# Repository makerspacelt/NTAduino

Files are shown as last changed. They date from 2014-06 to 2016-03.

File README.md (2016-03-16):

NTAduino
========

Repo for [No Trolls Allowed](http://notrollsallowed.com/) Arduino workshop

[NTA on GitHub](https://github.com/ntacamp)

### User notes
* Download USBasp drivers from [fischl.de](http://www.fischl.de/usbasp/usbasp-windriver.2011-05-28.zip).
* Copy NTAduino board description to boards.txt file from [here](https://github.com/makerspacelt/NTAduino/blob/master/arduino_patch/hardware/arduino/boards.txt)
* Press and hold reset button since board connecting to PC until all code is uploaded to the baord.

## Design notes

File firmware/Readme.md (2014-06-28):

NTAduino V0.1
====================
A project for [No Trolls allowed 2014](http://2014.notrollsallowed.com/)

Idea is to make a affordable, easy to make, minimal design arduino like board. And use it to teach people build and use it without any previous experience.

#### Usage ####
Firmware is stored into ATMega8 boot loader and acts as a USBasp programmer. To enter programing "upload" mode Hold SW1 (Refer to circuit diagram)

#### Compilation ####
- **make** - compile to hex binary
- **make flash** - write the boot loader
- **make fuse** - write fuse bits High: **0xC0** Low: **0x9F**

#### Licensing stuff ####
This project is a clone of [USBAspLoader](http://www.obdev.at/products/vusb/usbasploader.html) with a added small update
to accept SET_ISP_SCK instruction from avrdude (to remove the warning)

Which is build on [V-USB](http://www.obdev.at/products/vusb/index.html)
See *License.txt* fot a full license

#### Legal Disclaimer ####
We are not responsible for any possible damage or any other form of destruction.
If $*it will hit the fan while using this software we will not be held responsible for :)
Just don't ever divide by 0 on a ATMega

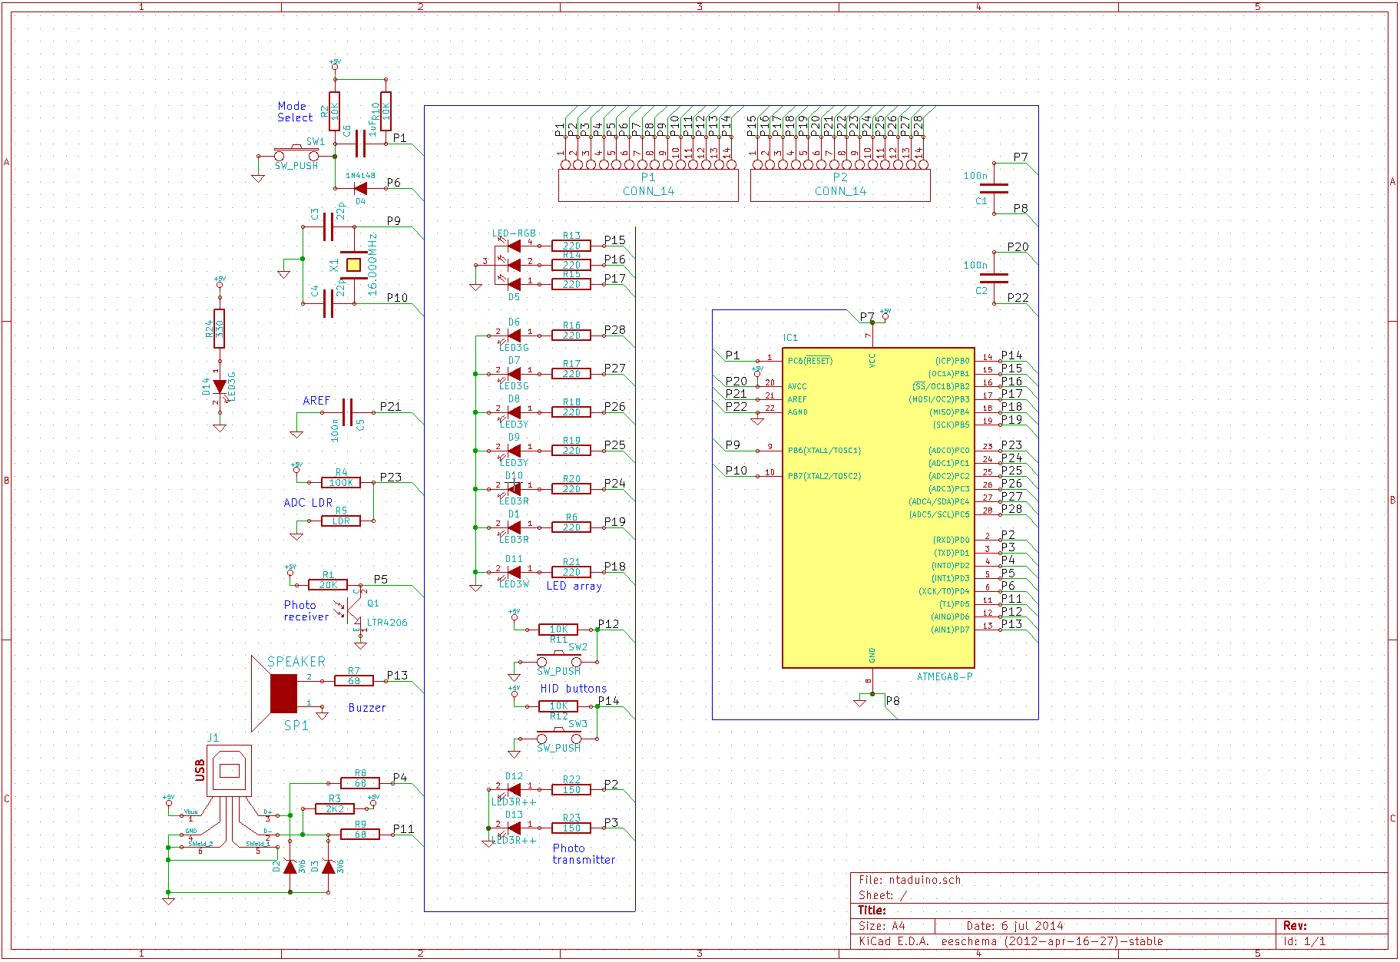
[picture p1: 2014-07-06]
images/sch.png

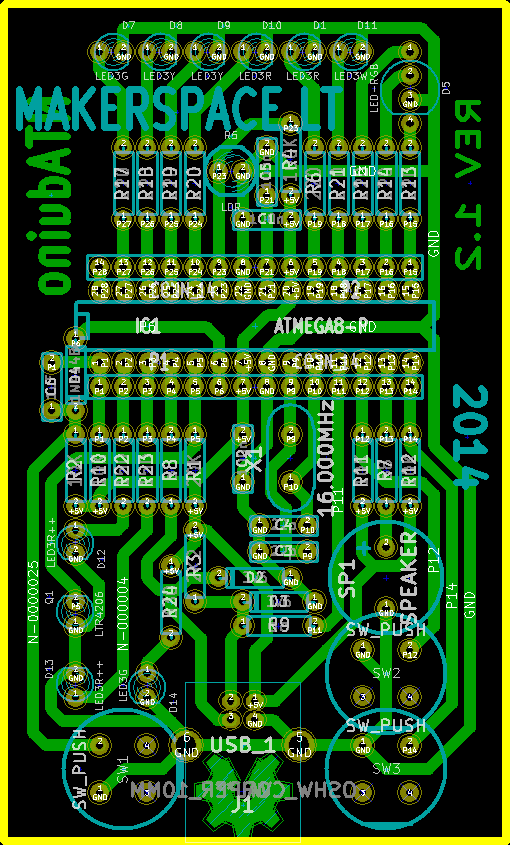
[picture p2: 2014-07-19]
images/pcb.png

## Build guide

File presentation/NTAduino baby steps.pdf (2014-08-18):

# NTAduino baby steps

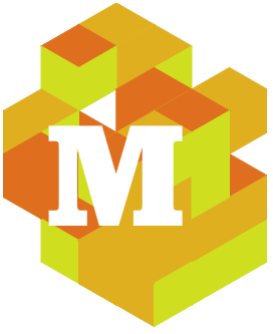
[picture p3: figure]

https://github.com/makerspacelt/NTAduino

# What is NTAduino?

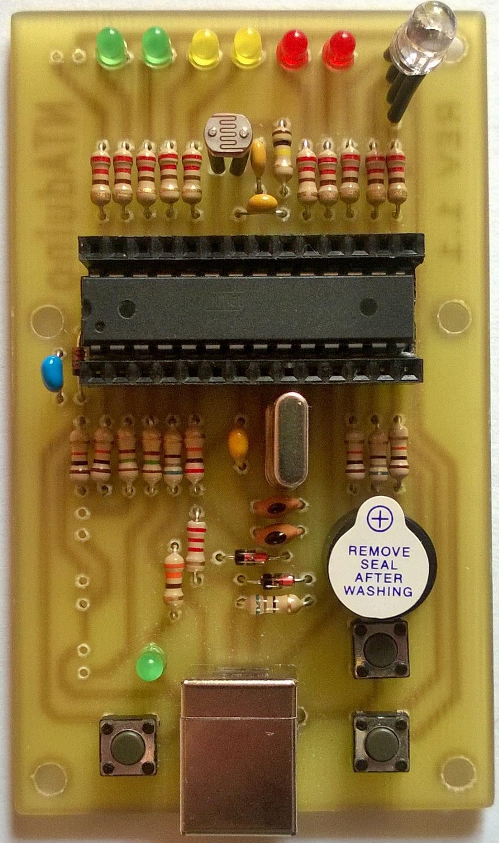
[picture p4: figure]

# Almost like Ardunio

### Advantages

- Single chip design
- All thru hole components
- Built in leds/buttons
- Cheap

### Disadvantages

- Has no usb -> uart support
- Single power option
- Needs a modified arduino IDE

# Getting started

1. Download arduino IDE :) http://arduino.cc/Main/Software
2. Download our patch
https://raw.githubusercontent.com/makerspacelt/NTAduino/master/arduino_patch/hardware/arduino/boards.txt (https://raw.githubusercontent.com/makerspacelt/NTAduino/master/arduino_patch/hardware/arduino/boards.txt)
3. Place the boards.txt into yout ardunino folder
arduino_location/hardware/arduino/b oards.txt
4. Launch Arduino ;)
5. From Tools->Board select NTAduino

# Coding NTAduino

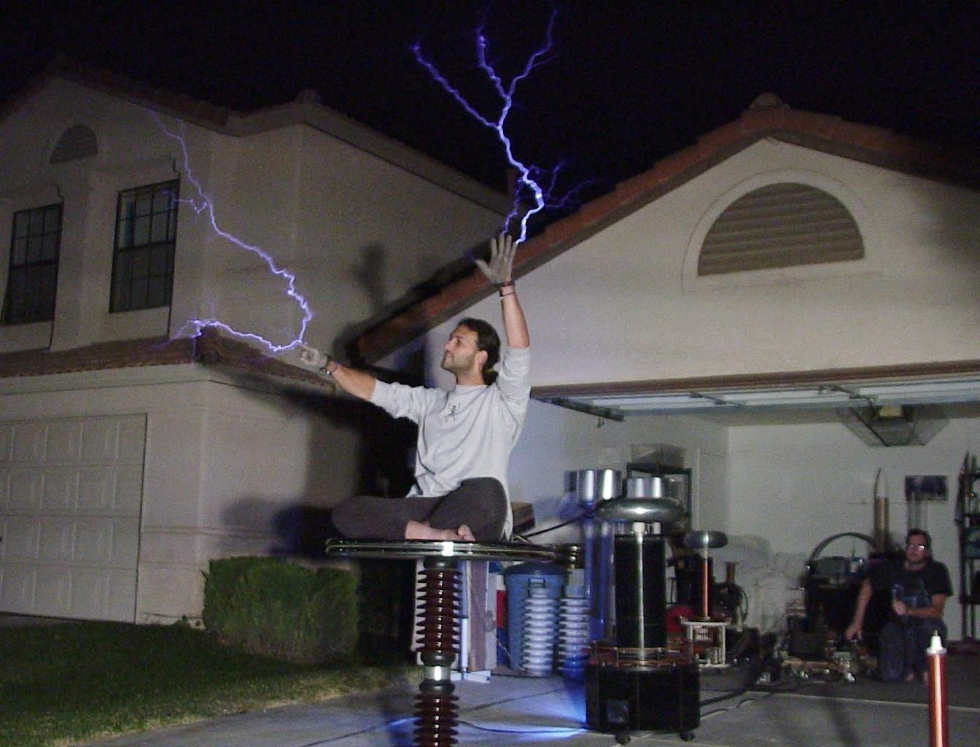
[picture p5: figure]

# Language

- Based on C programing language
- Everything starts in void setup()
- Everything runs in void loop()
- Programs are called sketches
- Great place to start is arduino example sketches

# Pins

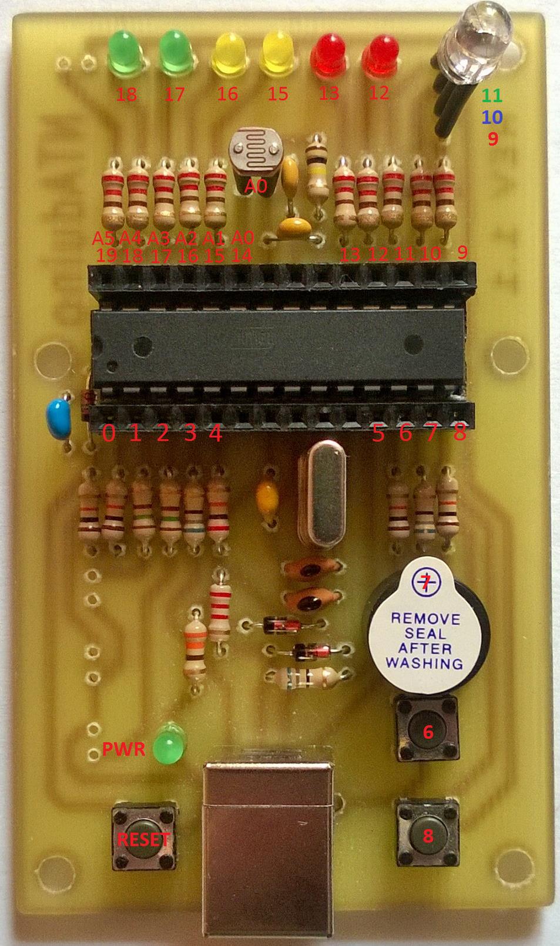
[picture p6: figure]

# Troubleshooting

### 1. Window could need a driver http://www.fischl.de/usbasp/ 2. Linux will probably need root permissions for usb

SUBSYSTEM=="usb",
ATTR{product}=="USBasp",
ATTR{idProduct}=="05dc",
ATTRS{idVendor}=="16c0",
MODE="0666"

# Workshop time

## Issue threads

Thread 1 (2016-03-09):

Could not get it running on Windows 8.1 nor Ubuntu

ViliusKraujutis, 2016-03-09:
Is it still possible to run it on Windows 8.1? Tried to install [USBASP](http://www.fischl.de/usbasp/) drivers by [disabling Windows' driver signature enforcement](https://openchrysalis.wordpress.com/2014/09/26/installing-usbasp-driver-software-in-windows-8-1/).

Error pops up like this:
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
Then information dialog:
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

Any ideas?

Matrooskin, 2016-03-10:
Yes, you can make work on latest Windows OS version. What a coincidence yesterday we run USBASP on Windows 10, even more we have compiled example and uploaded to original NTAduino board using latest Arduino IDE.

ViliusKraujutis, 2016-03-11:
@Matrooskin, could you please share link to USBASP? Maybe I've used incorrect version or so?

Matrooskin, 2016-03-11:
I think you are using same as we do from page [fischl.de](http://www.fischl.de/usbasp/usbasp-windriver.2011-05-28.zip). We are used "libusb_1.2.4.0" folder. As shown on wizard [page](https://openchrysalis.files.wordpress.com/2014/09/usbasp-driver-install-step-5.jpg) you need select correct path to drivers.
We restarted windows and after that connected NTAduino board to PC. After connecting to USB port you need press and hold programming button on NTAduino board until you install drivers.

ViliusKraujutis, 2016-03-13:
Aha! So pressing and holding programming button did the trick. Also I updated Windows 8.1 to Windows 10.

Now I see `USBasp` device in my devices list:
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

Although in `Arduino 1.6.8` IDE, menu `Tools`->`Ports` is grayed out. Hence I can't run any code on NTAduino yet. Do I need to prepare Arduino IDE more?

Matrooskin, 2016-03-14:
In that case you need update Arduino IDE configuration file. Go to {ARDUINO}/hardware/arduino/boards.txt where '{ARDUINO}' represents the directory into which the Arduino IDE and supporting files have been installed.
You need add this lines and restart IDE:
##############################################################
NTAduino.name=NTAduino

NTAduino.upload.tool=avrdude
NTAduino.upload.protocol=usbasp
NTAduino.upload.maximum_size=6388
NTAduino.upload.speed=19200

NTAduino.build.mcu=atmega8
NTAduino.build.f_cpu=16000000L
NTAduino.build.core=arduino
NTAduino.build.variant=standard

NTAduino.upload.disable_flushing=true
##############################################################

After restarting IDE you will see NTAduino on board choice. Plus you need select Programmer: "USBasp". When you want send program to board you need press and hold programming button until all data transfer to NTAduino.

Matrooskin, 2016-03-14:
On any Arduino IDE version you need choose only Board and Proggrammer. You don't need select port, because you are using USB, and USBasp must find port by self.

ViliusKraujutis, 2016-03-14:
Thanks, I managed to update code in NTAduino now. All works on my machine now. I used Arduino 1.6.0, as 1.6.8 could not recognize newly added NTAduino board.

Also, I noticed, that it's required ***to hold reset button since plugging board to the computer until all code is uploaded to the baord***.
Otherwise I would get this error:
>avrdude: Warning: cannot query manufacturer for device: libusb0-dll:err [control_msg] sending control message failed, win error: A device attached to the system is not functioning.

>avrdude: Warning: cannot query product for device: libusb0-dll:err [control_msg] sending control message failed, win error: A device attached to the system is not functioning.

>avrdude: error: could not find USB device with vid=0x16c0 pid=0x5dc vendor='www.fischl.de' product='USBasp'

Closed 2016-03-14.

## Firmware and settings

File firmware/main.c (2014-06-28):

/* Name: main.c
 * Project: USBaspLoader
 * Author: Christian Starkjohann
 * Creation Date: 2007-12-08
 * Tabsize: 4
 * Copyright: (c) 2007 by OBJECTIVE DEVELOPMENT Software GmbH
 * License: GNU GPL v2 (see License.txt)
 * This Revision: $Id$
 */

#include <avr/io.h>
#include <avr/interrupt.h>
#include <avr/pgmspace.h>
#include <avr/wdt.h>
#include <avr/boot.h>
#include <avr/eeprom.h>
#include <util/delay.h>
#include <string.h>

static void leaveBootloader() __attribute__((__noreturn__));

#include "bootloaderconfig.h"
#include "usbdrv/usbdrv.c"

/* ------------------------------------------------------------------------ */

/* Request constants used by USBasp */
#define USBASP_FUNC_CONNECT         1
#define USBASP_FUNC_DISCONNECT      2
#define USBASP_FUNC_TRANSMIT        3
#define USBASP_FUNC_READFLASH       4
#define USBASP_FUNC_ENABLEPROG      5
#define USBASP_FUNC_WRITEFLASH      6
#define USBASP_FUNC_READEEPROM      7
#define USBASP_FUNC_WRITEEEPROM     8
#define USBASP_FUNC_SETLONGADDRESS  9
#define USBASP_FUNC_SETISPSCK 10

/* ------------------------------------------------------------------------ */

#ifndef ulong
#   define ulong    unsigned long
#endif
#ifndef uint
#   define uint     unsigned int
#endif

/* defaults if not in config file: */
#ifndef HAVE_EEPROM_PAGED_ACCESS
#   define HAVE_EEPROM_PAGED_ACCESS 0
#endif
#ifndef HAVE_EEPROM_BYTE_ACCESS
#   define HAVE_EEPROM_BYTE_ACCESS  0
#endif
#ifndef BOOTLOADER_CAN_EXIT
#   define  BOOTLOADER_CAN_EXIT     0
#endif

/* allow compatibility with avrusbboot's bootloaderconfig.h: */
#ifdef BOOTLOADER_INIT
#   define bootLoaderInit()         BOOTLOADER_INIT
#   define bootLoaderExit()
#endif
#ifdef BOOTLOADER_CONDITION
#   define bootLoaderCondition()    BOOTLOADER_CONDITION
#endif

/* device compatibility: */
#ifndef GICR    /* ATMega*8 don't have GICR, use MCUCR instead */
#   define GICR     MCUCR
#endif

/* ------------------------------------------------------------------------ */

#if (FLASHEND) > 0xffff /* we need long addressing */
#   define CURRENT_ADDRESS  currentAddress.l
#   define addr_t           ulong
#else
#   define CURRENT_ADDRESS  currentAddress.w[0]
#   define addr_t           uint
#endif

typedef union longConverter{
    addr_t  l;
    uint    w[sizeof(addr_t)/2];
    uchar   b[sizeof(addr_t)];
}longConverter_t;

static uchar            requestBootLoaderExit;
static longConverter_t  currentAddress; /* in bytes */
static uchar            bytesRemaining;
static uchar            isLastPage;
#if HAVE_EEPROM_PAGED_ACCESS
static uchar            currentRequest;
#else
static const uchar      currentRequest = 0;
#endif

static const uchar  signatureBytes[4] = {
#ifdef SIGNATURE_BYTES
    SIGNATURE_BYTES
#elif defined (__AVR_ATmega8__) || defined (__AVR_ATmega8HVA__)
    0x1e, 0x93, 0x07, 0
#elif defined (__AVR_ATmega48__) || defined (__AVR_ATmega48P__)
    0x1e, 0x92, 0x05, 0
#elif defined (__AVR_ATmega88__) || defined (__AVR_ATmega88P__)
    0x1e, 0x93, 0x0a, 0
#elif defined (__AVR_ATmega168__) || defined (__AVR_ATmega168P__)
    0x1e, 0x94, 0x06, 0
#elif defined (__AVR_ATmega328P__)
    0x1e, 0x95, 0x0f, 0
#else
#   error "Device signature is not known, please edit main.c!"
#endif
};

/* ------------------------------------------------------------------------ */

static void (*nullVector)(void) __attribute__((__noreturn__));

static void leaveBootloader()
{
    DBG1(0x01, 0, 0);
    bootLoaderExit();
    cli();
    USB_INTR_ENABLE = 0;
    USB_INTR_CFG = 0;       /* also reset config bits */
    GICR = (1 << IVCE);     /* enable change of interrupt vectors */
    GICR = (0 << IVSEL);    /* move interrupts to application flash section */
/* We must go through a global function pointer variable instead of writing
 *  ((void (*)(void))0)();
 * because the compiler optimizes a constant 0 to "rcall 0" which is not
 * handled correctly by the assembler.
 */
    nullVector();
}

/* ------------------------------------------------------------------------ */

uchar   usbFunctionSetup(uchar data[8])
{
usbRequest_t    *rq = (void *)data;
uchar           len = 0;
static uchar    replyBuffer[4];

    usbMsgPtr = (usbMsgPtr_t)replyBuffer;
    if(rq->bRequest == USBASP_FUNC_TRANSMIT){   /* emulate parts of ISP protocol */
        uchar rval = 0;
        usbWord_t address;
        address.bytes[1] = rq->wValue.bytes[1];
        address.bytes[0] = rq->wIndex.bytes[0];
        if(rq->wValue.bytes[0] == 0x30){        /* read signature */
            rval = rq->wIndex.bytes[0] & 3;
            rval = signatureBytes[rval];
#if HAVE_EEPROM_BYTE_ACCESS
        }else if(rq->wValue.bytes[0] == 0xa0){  /* read EEPROM byte */
            rval = eeprom_read_byte((void *)address.word);
        }else if(rq->wValue.bytes[0] == 0xc0){  /* write EEPROM byte */
            eeprom_write_byte((void *)address.word, rq->wIndex.bytes[1]);
#endif
#if HAVE_CHIP_ERASE
        }else if(rq->wValue.bytes[0] == 0xac && rq->wValue.bytes[1] == 0x80){  /* chip erase */
            addr_t addr;
            for(addr = 0; addr < FLASHEND + 1 - 2048; addr += SPM_PAGESIZE) {
                /* wait and erase page */
                DBG1(0x33, 0, 0);
#   ifndef NO_FLASH_WRITE
                boot_spm_busy_wait();
                cli();
                boot_page_erase(addr);
                sei();
#   endif
            }
#endif
        }else{
            /* ignore all others, return default value == 0 */
        }
        replyBuffer[3] = rval;
        len = 4;
    }else if(rq->bRequest == USBASP_FUNC_ENABLEPROG){
        /* replyBuffer[0] = 0; is never touched and thus always 0 which means success */
        len = 1;
    }else if(rq->bRequest >= USBASP_FUNC_READFLASH && rq->bRequest <= USBASP_FUNC_SETLONGADDRESS){
        currentAddress.w[0] = rq->wValue.word;
        if(rq->bRequest == USBASP_FUNC_SETLONGADDRESS){
#if (FLASHEND) > 0xffff
            currentAddress.w[1] = rq->wIndex.word;
#endif
        }else{
            bytesRemaining = rq->wLength.bytes[0];
            /* if(rq->bRequest == USBASP_FUNC_WRITEFLASH) only evaluated during writeFlash anyway */
            isLastPage = rq->wIndex.bytes[1] & 0x02;
#if HAVE_EEPROM_PAGED_ACCESS
            currentRequest = rq->bRequest;
#endif
            len = 0xff; /* hand over to usbFunctionRead() / usbFunctionWrite() */
        }
#if BOOTLOADER_CAN_EXIT
    }else if(rq->bRequest == USBASP_FUNC_DISCONNECT){
        requestBootLoaderExit = 1;      /* allow proper shutdown/close of connection */
#endif
	}else if (rq->bRequest == USBASP_FUNC_SETISPSCK){
	/* A dummy response when avrdude requests to set programming speed. As bootloader doesn't use any real lines */
		replyBuffer[0] = 0;
		len = 1;
    }else{
        /* ignore: USBASP_FUNC_CONNECT */
    }
    return len;
}

uchar usbFunctionWrite(uchar *data, uchar len)
{
uchar   isLast;

    DBG1(0x31, (void *)&currentAddress.l, 4);
    if(len > bytesRemaining)
        len = bytesRemaining;
    bytesRemaining -= len;
    isLast = bytesRemaining == 0;
    if(currentRequest >= USBASP_FUNC_READEEPROM){
        uchar i;
        for(i = 0; i < len; i++){
            eeprom_write_byte((void *)(currentAddress.w[0]++), *data++);
        }
    }else{
        uchar i;
        for(i = 0; i < len;){
#if !HAVE_CHIP_ERASE
            if((currentAddress.w[0] & (SPM_PAGESIZE - 1)) == 0){    /* if page start: erase */
                DBG1(0x33, 0, 0);
#   ifndef NO_FLASH_WRITE
                cli();
                boot_page_erase(CURRENT_ADDRESS);   /* erase page */
                sei();
                boot_spm_busy_wait();               /* wait until page is erased */
#   endif
            }
#endif
            i += 2;
            DBG1(0x32, 0, 0);
            cli();
            boot_page_fill(CURRENT_ADDRESS, *(short *)data);
            sei();
            CURRENT_ADDRESS += 2;
            data += 2;
            /* write page when we cross page boundary or we have the last partial page */
            if((currentAddress.w[0] & (SPM_PAGESIZE - 1)) == 0 || (isLast && i >= len && isLastPage)){
                DBG1(0x34, 0, 0);
#ifndef NO_FLASH_WRITE
                cli();
                boot_page_write(CURRENT_ADDRESS - 2);
                sei();
                boot_spm_busy_wait();
                cli();
                boot_rww_enable();
                sei();
#endif
            }
        }
        DBG1(0x35, (void *)&currentAddress.l, 4);
    }
    return isLast;
}

uchar usbFunctionRead(uchar *data, uchar len)
{
uchar   i;

    if(len > bytesRemaining)
        len = bytesRemaining;
    bytesRemaining -= len;
    for(i = 0; i < len; i++){
        if(currentRequest >= USBASP_FUNC_READEEPROM){
            *data = eeprom_read_byte((void *)currentAddress.w[0]);
        }else{
            *data = pgm_read_byte((void *)CURRENT_ADDRESS);
        }
        data++;
        CURRENT_ADDRESS++;
    }
    return len;
}

/* ------------------------------------------------------------------------ */

static void initForUsbConnectivity(void)
{
uchar   i = 0;

    usbInit();
    /* enforce USB re-enumerate: */
    usbDeviceDisconnect();  /* do this while interrupts are disabled */
    while(--i){         /* fake USB disconnect for > 250 ms */
        wdt_reset();
        _delay_ms(1);
    }
    usbDeviceConnect();
    sei();
}

int __attribute__((noreturn)) main(void)
{
    /* initialize  */
    wdt_disable();      /* main app may have enabled watchdog */
    bootLoaderInit();
    odDebugInit();
    DBG1(0x00, 0, 0);
#ifndef NO_FLASH_WRITE
    GICR = (1 << IVCE);  /* enable change of interrupt vectors */
    GICR = (1 << IVSEL); /* move interrupts to boot flash section */
#endif
    if(bootLoaderCondition()){
        uchar i = 0, j = 0;
        initForUsbConnectivity();
        do{
            usbPoll();
#if BOOTLOADER_CAN_EXIT
            if(requestBootLoaderExit){
                if(--i == 0){
                    if(--j == 0)
                        break;
                }
            }
#endif
        }while(bootLoaderCondition());  /* main event loop */
    }
    leaveBootloader();
}

/* ------------------------------------------------------------------------ */

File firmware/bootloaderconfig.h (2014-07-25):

/* Name: bootloaderconfig.h
 * Project: USBaspLoader
 * Author: Christian Starkjohann
 * Creation Date: 2007-12-08
 * Tabsize: 4
 * Copyright: (c) 2007 by OBJECTIVE DEVELOPMENT Software GmbH
 * License: GNU GPL v2 (see License.txt)
 * This Revision: $Id$
 */

#ifndef __bootloaderconfig_h_included__
#define __bootloaderconfig_h_included__

/*
General Description:
This file (together with some settings in Makefile) configures the boot loader
according to the hardware.

This file contains (besides the hardware configuration normally found in
usbconfig.h) two functions or macros: bootLoaderInit() and
bootLoaderCondition(). Whether you implement them as macros or as static
inline functions is up to you, decide based on code size and convenience.

bootLoaderInit() is called as one of the first actions after reset. It should
be a minimum initialization of the hardware so that the boot loader condition
can be read. This will usually consist of activating a pull-up resistor for an
external jumper which selects boot loader mode.

bootLoaderCondition() is called immediately after initialization and in each
main loop iteration. If it returns TRUE, the boot loader will be active. If it
returns FALSE, the boot loader jumps to address 0 (the loaded application)
immediately.

For compatibility with Thomas Fischl's avrusbboot, we also support the macro
names BOOTLOADER_INIT and BOOTLOADER_CONDITION for this functionality. If
these macros are defined, the boot loader usees them.
*/

/* ---------------------------- Hardware Config ---------------------------- */

#define USB_CFG_IOPORTNAME      D
/* This is the port where the USB bus is connected. When you configure it to
 * "B", the registers PORTB, PINB and DDRB will be used.
 */
#define USB_CFG_DMINUS_BIT      5
/* This is the bit number in USB_CFG_IOPORT where the USB D- line is connected.
 * This may be any bit in the port.
 */
#define USB_CFG_DPLUS_BIT       2
/* This is the bit number in USB_CFG_IOPORT where the USB D+ line is connected.
 * This may be any bit in the port. Please note that D+ must also be connected
 * to interrupt pin INT0!
 */
#define USB_CFG_CLOCK_KHZ       (F_CPU/1000)
/* Clock rate of the AVR in MHz. Legal values are 12000, 16000 or 16500.
 * The 16.5 MHz version of the code requires no crystal, it tolerates +/- 1%
 * deviation from the nominal frequency. All other rates require a precision
 * of 2000 ppm and thus a crystal!
 * Default if not specified: 12 MHz
 */

/* ----------------------- Optional Hardware Config ------------------------ */

/* #define USB_CFG_PULLUP_IOPORTNAME   D */
/* If you connect the 1.5k pullup resistor from D- to a port pin instead of
 * V+, you can connect and disconnect the device from firmware by calling
 * the macros usbDeviceConnect() and usbDeviceDisconnect() (see usbdrv.h).
 * This constant defines the port on which the pullup resistor is connected.
 */
/* #define USB_CFG_PULLUP_BIT          5 */
/* This constant defines the bit number in USB_CFG_PULLUP_IOPORT (defined
 * above) where the 1.5k pullup resistor is connected. See description
 * above for details.
 */

/* ------------------------------------------------------------------------- */
/* ---------------------- feature / code size options ---------------------- */
/* ------------------------------------------------------------------------- */

#define HAVE_EEPROM_PAGED_ACCESS    0
/* If HAVE_EEPROM_PAGED_ACCESS is defined to 1, page mode access to EEPROM is
 * compiled in. Whether page mode or byte mode access is used by AVRDUDE
 * depends on the target device. Page mode is only used if the device supports
 * it, e.g. for the ATMega88, 168 etc. You can save quite a bit of memory by
 * disabling page mode EEPROM access. Costs ~ 138 bytes.
 */
#define HAVE_EEPROM_BYTE_ACCESS     1
/* If HAVE_EEPROM_BYTE_ACCESS is defined to 1, byte mode access to EEPROM is
 * compiled in. Byte mode is only used if the device (as identified by its
 * signature) does not support page mode for EEPROM. It is required for
 * accessing the EEPROM on the ATMega8. Costs ~54 bytes.
 */
#define BOOTLOADER_CAN_EXIT         1
/* If this macro is defined to 1, the boot loader will exit shortly after the
 * programmer closes the connection to the device. Costs ~36 bytes.
 */
#define HAVE_CHIP_ERASE             0
/* If this macro is defined to 1, the boot loader implements the Chip Erase
 * ISP command. Otherwise pages are erased on demand before they are written.
 */
//#define SIGNATURE_BYTES             0x1e, 0x93, 0x07, 0     /* ATMega8 */
/* This macro defines the signature bytes returned by the emulated USBasp to
 * the programmer software. They should match the actual device at least in
 * memory size and features. If you don't define this, values for ATMega8,
 * ATMega88, ATMega168 and ATMega328 are guessed correctly.
 */
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

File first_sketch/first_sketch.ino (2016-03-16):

#include "pitches.h"

// arduino pins for 6 leds
const int leds[] = {18, 17, 16, 15, 13, 12}; 

// rgb led pins
const int rgb[] = {9, 10, 11};

// melody :D
const int melody[] = {NOTE_C4, NOTE_G3, NOTE_G3, NOTE_A3, NOTE_G3, 0, NOTE_B3, NOTE_C4};
const int noteDurations[] = {4, 8, 8, 4,4,4,4,4 };

// speaker pin
const int speaker = 7;

// upper button pin
const int button = 6;

// ldr pin
const int ldr = A0;

// program counters and initial states
int test = 0;
int curRgb = 0;
int ledCnt = 6;
int curLed = 0;
int stepDir = 1;
int curNote = 0;
int notes = 8;

int curButtonState = 1;
int buttonLocked = 0;
long lastDebounceTime = 0;
int debounceDelay = 10;

void setup()
{
   for (int i = 0; i < 6; i++) {
     pinMode(leds[i], OUTPUT);
   }
   
   for (int i = 0; i < 3; i++) {
     pinMode(rgb[i], OUTPUT);
   }
   
   pinMode(button, INPUT);
}

void loop()
{
  // button debouncing
  curButtonState = digitalRead(button);
  if (curButtonState == LOW) {
    if (lastDebounceTime == 0) {
      lastDebounceTime = millis();
    } else if (millis() - lastDebounceTime >= debounceDelay && !buttonLocked) {
      buttonLocked  = 1;
      test ++;
      if (test > 3) {
        test = 0;
      }
      
      // test changed, clean everything
      noTone(speaker);
      cleanPins();
      curRgb = 0;
      curLed = 0;
      stepDir = 1;
      curNote = 0;
    }
  } else {
    lastDebounceTime = 0;
    buttonLocked = 0;
  }
  
  // what test to run?
  switch(test) {
    case 0:
      test1();
      break;
    case 1:
      test2();
      break;
    case 2:
      test3();
      break;  
    case 3:
      test4();
      break;     
  }
}

// helper function for reseting states on pins
void cleanPins()
{
  noTone(speaker);
  
  for (int i = 0; i < ledCnt; i++) {
    digitalWrite(leds[i], LOW);
  }
  
  for (int i = 0; i < 3; i++) {
    digitalWrite(rgb[i], LOW);
  }
}

// led follower
void test1()
{
  cleanPins();
  
  digitalWrite(leds[curLed], HIGH);
  
  curLed += stepDir;
  
  if (curLed >= ledCnt) {
    curLed = ledCnt - 2;
    stepDir = -stepDir;
    
    digitalWrite(rgb[curRgb], HIGH);
    curRgb++;
    if (curRgb > 2) {
      curRgb = 0;
    }
  }
  
  if (curLed == 0) {
    stepDir = -stepDir;
  }
  
  delay(100);
}

// melody
void test2()
{
    int noteDuration = 1000/noteDurations[curNote];
    tone(speaker, melody[curNote], noteDuration);

    int pauseBetweenNotes = noteDuration * 1.30;
    delay(pauseBetweenNotes);
    noTone(speaker);
    
    curNote++;
    if (curNote >= notes) {
      curNote = 0;
    }
}

// ldr graph
void test3()
{
  int lightValue = analogRead(ldr);
  cleanPins();
  int output = map(lightValue, 0, 900, 0, 6);
  if (output > 0) {
    for (int i = 0; i <= output - 1; i++) {
      digitalWrite(leds[i], HIGH);
    }
  }
}

// inverted ldr graph
void test4()
{
  int lightValue = analogRead(ldr);
  cleanPins();
  int output = map(lightValue, 800, 0, 0, 6);
  if (output > 0) {
    for (int i = 0; i <= output - 1; i++) {
      digitalWrite(leds[i], HIGH);
    }
  }
  if (lightValue < 50) {
    digitalWrite(rgb[curRgb], HIGH);
    curRgb++;
    if (curRgb > 2) {
      curRgb = 0;
    }
  }
  delay(100);
}

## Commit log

2014-03-22 created schematics with few main parts
    [ntaduino.sch]
2014-06-28 Adding NTAduino real board v0.1
    [ntaduino.sch]
2014-06-28 Adding arduino boards.txt
2014-07-05 adding some kicad files to gitignore
2014-07-05 populating schematics and associating footprints
    [ntaduino.brd, ntaduino.sch]
2014-07-05 adding schematics image for easy reviewing
2014-07-06 preliminary PCB layout with minor schematics changes
    [ntaduino.brd, ntaduino.sch]
2014-07-08 connecting commponents on the pcb and adding pcb image
    [ntaduino.brd, ntaduino.sch]
2014-07-10 Board rev 1.1 Changed pad sizes: drill 1mm, pad 2mm Changed some cramped footprints USB footprint redesign
    [ntaduino.brd]
2014-07-10 Adapting bootloader with PCB
2014-07-19 Rev 1.2
    [ntaduino.brd, ntaduino.sch]
2014-07-25 Adding small fixes and a silkscreen
    [ntaduino.brd]
2016-03-14 Notes after connecting board 2y later
2016-03-14 Add inverted LDR graph test method
    [first_sketch.ino]
